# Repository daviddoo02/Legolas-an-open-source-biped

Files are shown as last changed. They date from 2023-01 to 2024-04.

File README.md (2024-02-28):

# Legolas - An Open Source Bipedal Robot

Legolas is a mini bipedal robot inspired by the Cassie by Agility Robotics. The project aims to provide an open-source platform for learning and applying reinforcement learning in robotics.

<p align="center">
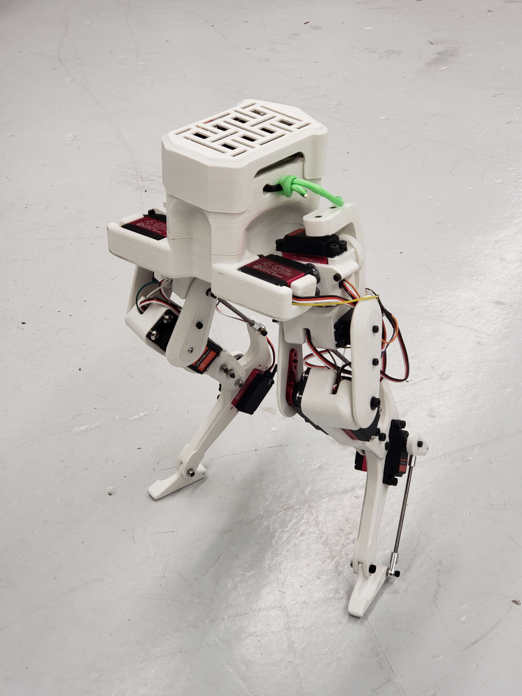
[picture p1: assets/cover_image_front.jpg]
  
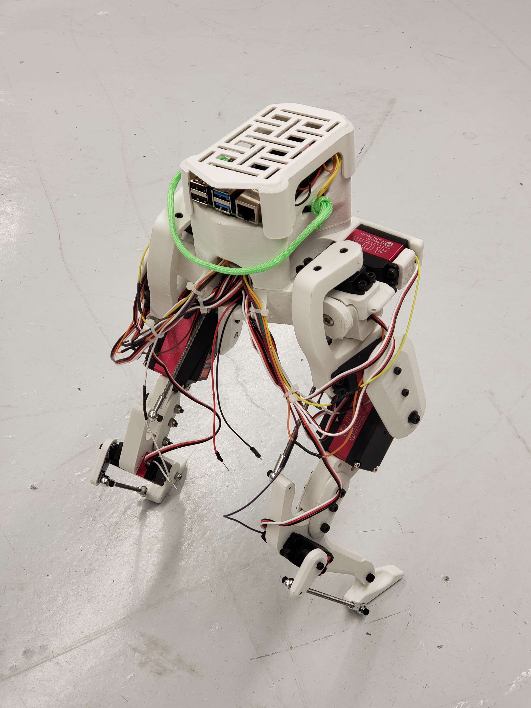
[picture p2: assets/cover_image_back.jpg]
  
</p>

<p align="center">
  <a href="assets/Walking_Test_3.mp4">Video 3</a>
</p>

## Repository Contents

This repository contains CAD files and 3D printing files for Legolas. 

The code for the robot is available at [Legolas Controller](https://github.com/daviddoo02/Legolas_Controller).

## Getting Started

1. **Clone this repository:**

    ```bash
    git clone https://github.com/daviddoo02/Legolas-an-open-source-biped/
    ```

2. **Modify the CAD files:**

    Modify the CAD files to fit your specific needs using Solidworks.

3. **3D Print your own robot:**

    Alternatively, use the provided STL files located in `CAD/Legolas/V2/STLs` to 3D print your own robot.

4. **Assemble the robot and have fun!**

## Required Materials

Materials and components used are listed and linked below.

### Main Body

1. [3D printing filament x 1 kg](https://www.amazon.com/dp/B089S1HB8K)
2. [Metric Nuts and Bolts](https://www.amazon.com/Assortment-M2-M3-M4-M5/dp/B0CBMMPPKF)
3. [Metric Locknuts](https://www.amazon.com/dp/B0CHVTYLWC)
4. [Thrust Bearings](https://www.amazon.com/gp/product/B08FHTD8VT)
5. [Ball joint rod end](https://www.amazon.com/gp/product/B0828T1NNW)
6. [M4 threaded rod](https://www.amazon.com/gp/product/B01MAYQ12S)

### Electronics

1. [Raspberry Pi 4](https://www.amazon.com/Raspberry-Model-2019-Quad-Bluetooth/dp/B07TC2BK1X)
2. [PCA9685 Servo Driver Board](https://www.amazon.com/gp/product/B07BRS249H)
3. [40 kg Hobby Servos x 8](https://www.amazon.com/Servo-Torque-Waterproof-Degree-Compatible/dp/B0C95YMMQS)
4. [80 kg Hobby Servos x 2](https://www.amazon.com/GoolRC-Digital-Torque-Waterproof-Replacements/dp/B0B5H4MWZG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)
5. [MPU6050 IMU](https://www.amazon.com/Acceleration-Sensors-Accelerometer-Three-Axis-Quadcopter/dp/B07V67DQ5N)
6. [ADS1115 ADC](https://www.amazon.com/gp/product/B07VPFLSMX)
7. [Jumper Wires](https://www.amazon.com/Elegoo-EL-CP-004-Multicolored-Breadboard-arduino/dp/B01EV70C78)
8. [Power DIY Connector](https://www.amazon.com/dp/B09S3S6RYC)
9. [USB C Connector](https://www.amazon.com/dp/B0CCJRWKC5)
10. [4 to 1 Wire Connector](https://www.amazon.com/dp/B0B28GNVGZ)

## Assembly Instruction

Instructions and examples for assembling Legolas will be added in future updates.

## License

This project is licensed under the MIT License - see the [LICENSE](LICENSE) file for details.

## Acknowledgments

- Inspired by the Cassie robot by Agility Robotics.
- Solidworks was used for the physical design of the robot.

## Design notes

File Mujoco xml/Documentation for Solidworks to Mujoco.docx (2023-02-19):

Documentation for Solidworks to Mujoco:

1. Exporting from Solidworks using SW2URDF:
  a. Step 1: Download SW2URDF extension
    i. Repo: https://github.com/ros/solidworks_urdf_exporter/releases
  b. Step 2: Assigning frames to your robot
    i. (170) Frame Assignment For Robotic Manipulators - Direct Kinematics I - YouTube (https://www.youtube.com/watch?v=fNIyNF87q9I&t=244s)
    ii. ^ this video should give you a good idea of what assigning frames is and how to know where to place your frames.
    iii. Use the Reference geometry → Coordinate system tool in Solidworks.
      1. A useful tip: Point your coordinate systems toward each other if possible – this will make it easier to code in mujoco later.
  c. Step 3: Using the extension
    i. Follow this video tutorial: https://www.youtube.com/watch?v=ge3P307TgJI
    ii. Now you should have a folder with the URDF of your robot.
2. Accessing the URDF and verifying the urdf:
  a. Ref:
    i. https://mujoco.readthedocs.io/en/latest/modeling.html#curdf
    ii. urdf - ROS Wiki (http://wiki.ros.org/urdf)
  b. Step 1: Checking if your URDF generated correctly:
    i. Add the mujoco extension after robot name like so:

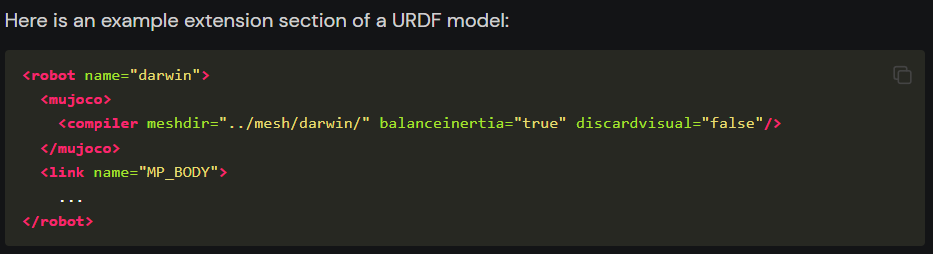
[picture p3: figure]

  c. Step 2: Check the URDF for collision/joint problems:
    i. After you add the extension, you should be able to drag and drop the file into mujoco and 2 things can happen:
      1. Everything runs < less interesting
      2. Everything runs itself apart < more interesting
        a. If this was the case, you could be running into a collision issue.
        b. You can confirm this by tapping F to toggle the forces vectors and H to toggle the convex hull

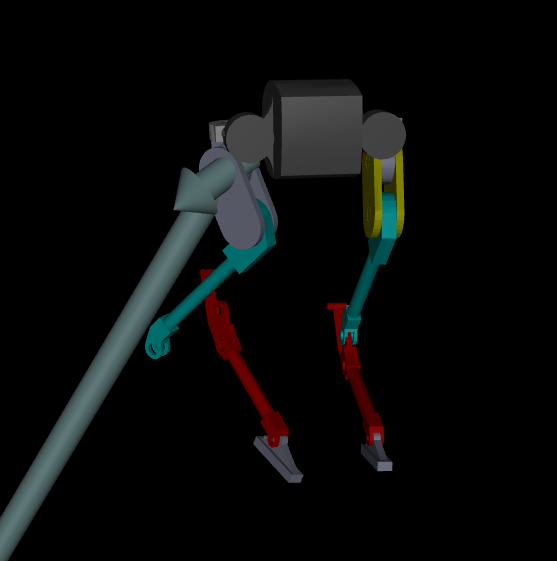
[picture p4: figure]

          ii. So, as you can see, there is a huge force coming off the body and the knee joint not being connected.
    ii. Fixing Joints:
      1. Go back to Solidworks and check how the urdf was generated, make sure all the frames and joint types are correct and regenerate the urdf.
    iii. Fixing collision:
      1. Check which part is colliding by hitting the H-key on your keyboard.
        a. Note: if a collision geometry was not specified, mujoco will automatically generate it, but it messes up sometimes.
      2. Solution: in the URDF, replace the collision mesh with something else by changing the name of the collision geometry mesh to the new mesh.
  d. Step 3: Verifying your URDF on Linux:
    i. Use the following command on Linux terminal to verify the URDF:
      1. rosrun urdfdom check_urdf /path2model/<model>.urdf
    ii. This should output the kinematic tree of your robot.

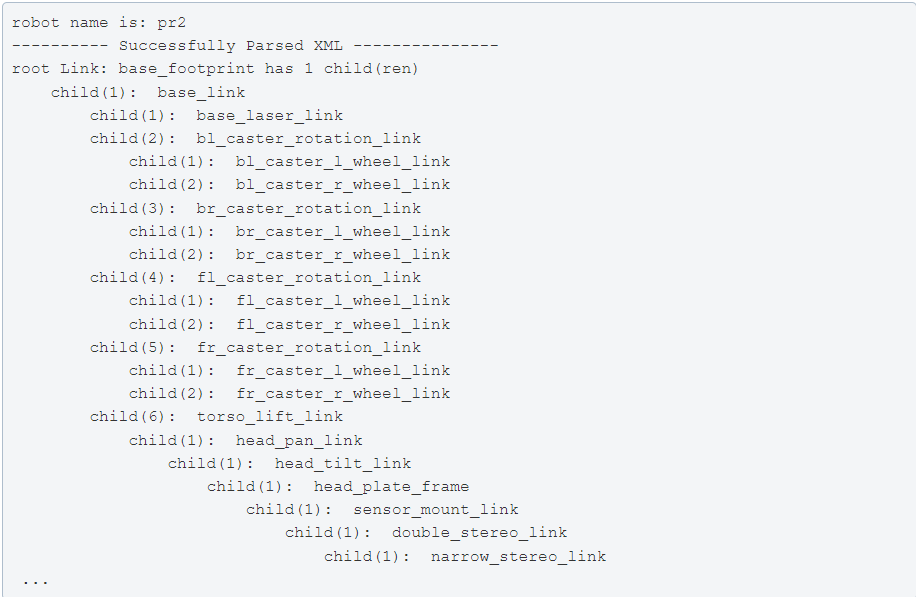
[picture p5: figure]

3. Converting URDF to MUJOCO xml:
  a. Ref:
    i. wangcongrobot/dual_ur5_husky_mujoco: Dual UR5 Husky Robot MuJoCo Model (github.com) (https://github.com/wangcongrobot/dual_ur5_husky_mujoco)
  b. Enter the path ~/mujoco/mujoco200/bin first and run command below:
  c. Convert the urdf:
    i. compile /path/to/model.urdf /path/to/model.xml
  d. Test:
    i. mujoco200/bin$ ./simulate /path/to/model.xml

Congratulations! You are now able to run mujoco with your robot design! Add more mujoco tags as needed

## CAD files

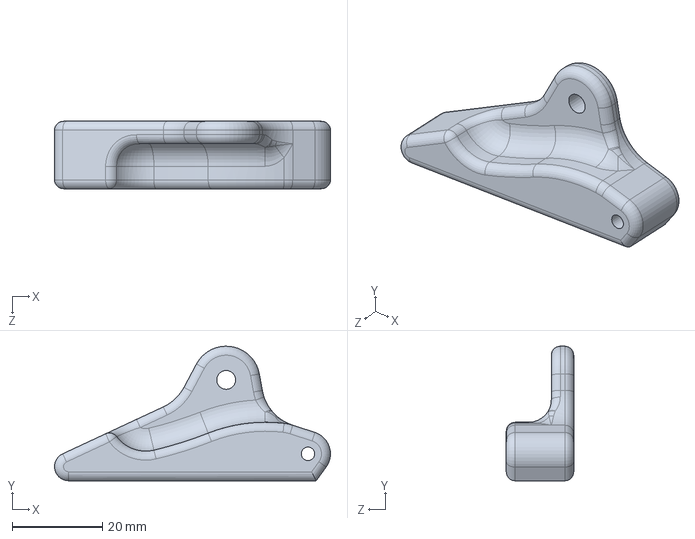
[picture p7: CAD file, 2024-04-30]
CAD/Legolas/V3/Foot v3.SLDPRT
61.3 x 29.9 x 15.0 mm

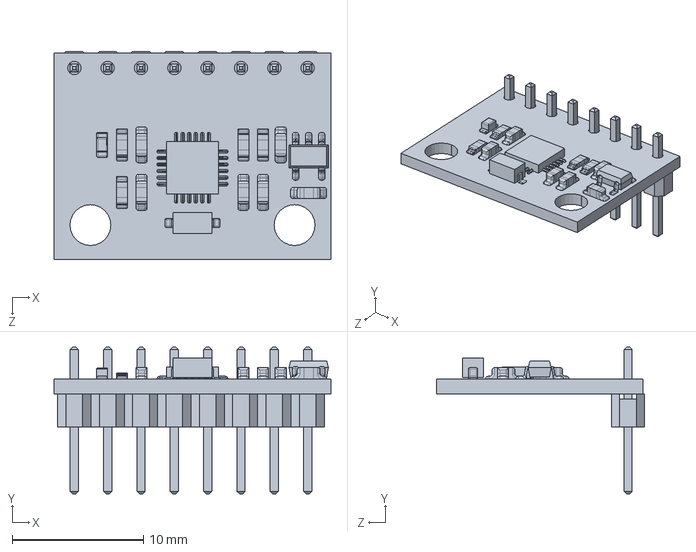
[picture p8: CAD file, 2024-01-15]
CAD/Servo and electronics/MPU 6050 IMU.SLDPRT
21.1 x 11.2 x 15.9 mm

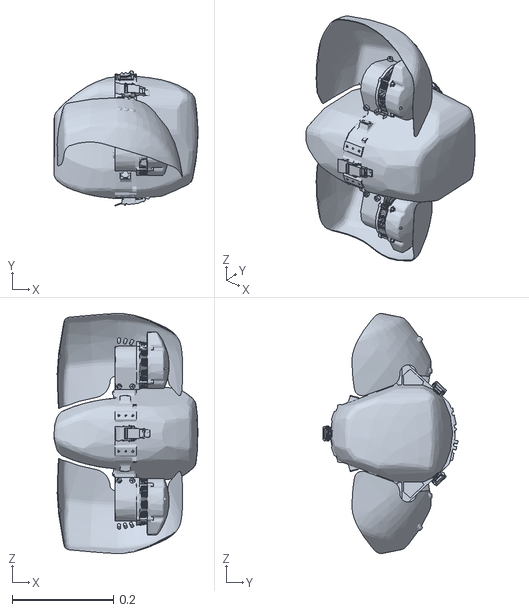
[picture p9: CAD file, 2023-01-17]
Mujoco xml/References/agility_cassie/assets/pelvis.obj
0.284 x 0.267 x 0.474

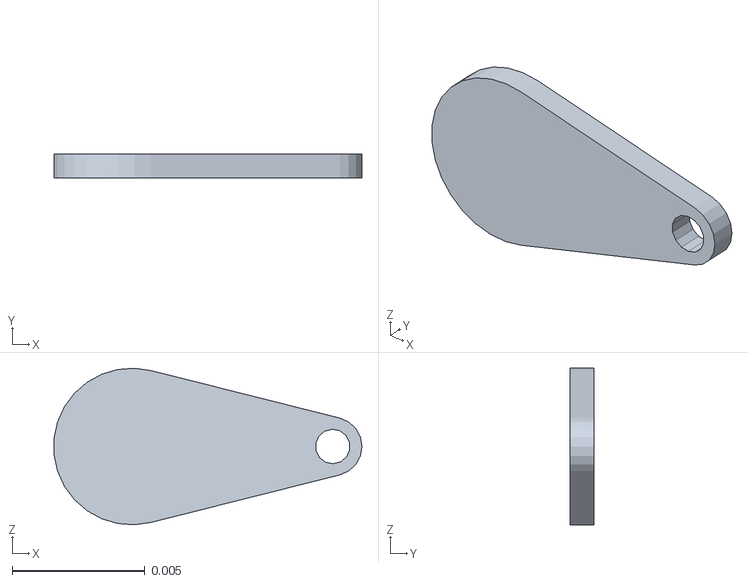
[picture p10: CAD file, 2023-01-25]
Working Mk 5/meshes/R_Servo_collision.STL
0.0116 x 0.000898 x 0.00589

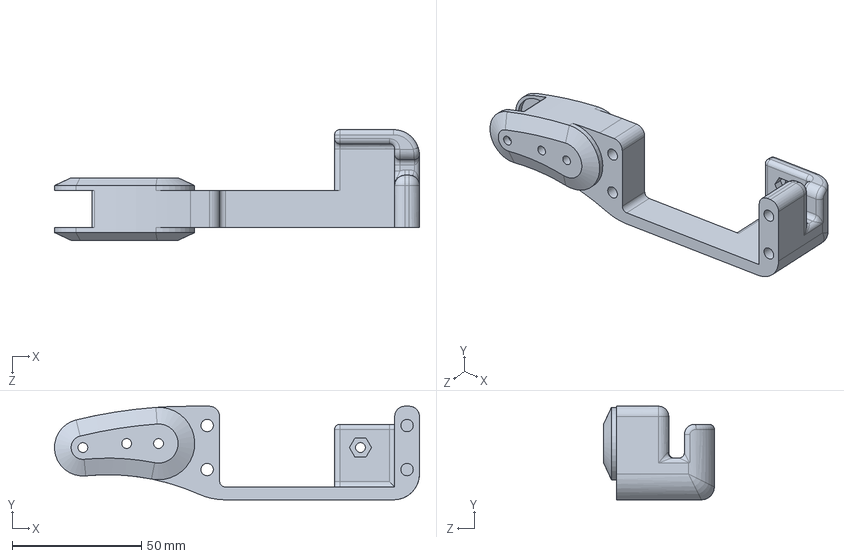
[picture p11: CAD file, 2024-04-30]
CAD/Legolas/V3/Foreleg v3.SLDPRT
141.0 x 36.2 x 42.8 mm

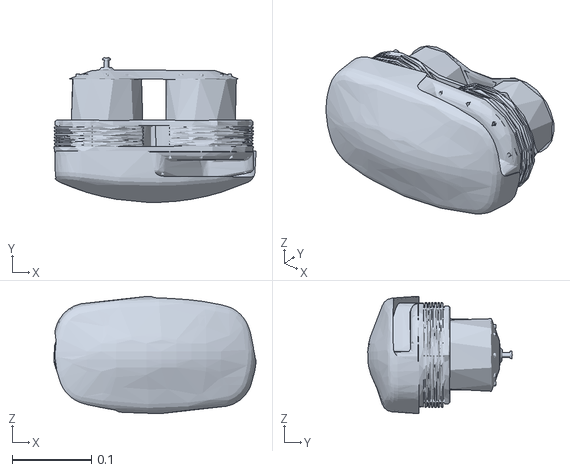
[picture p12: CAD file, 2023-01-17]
Mujoco xml/References/agility_cassie/assets/hip-pitch.obj
0.256 x 0.183 x 0.149

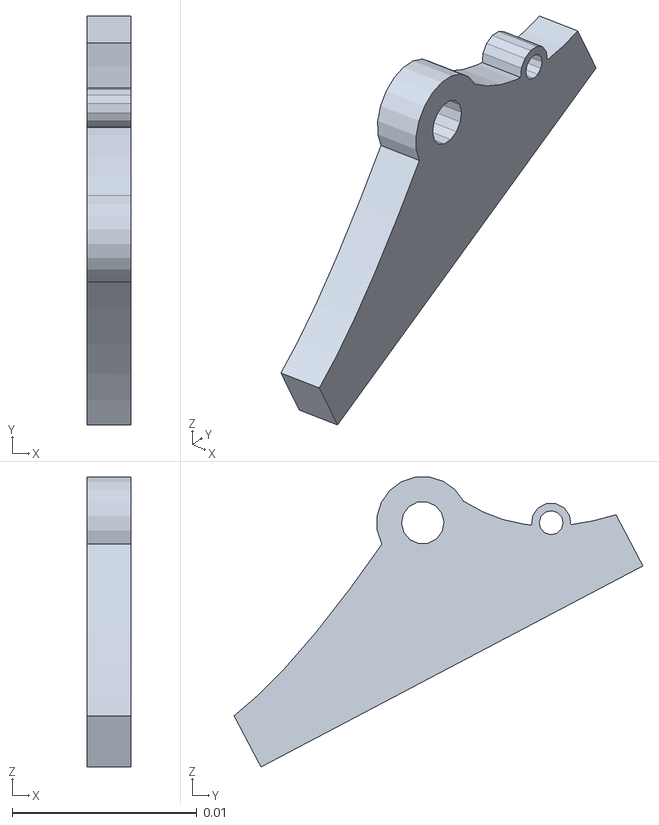
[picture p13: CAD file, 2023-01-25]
Working Mk 5/meshes/R_Foot_collision.STL
0.0024 x 0.0221 x 0.0157

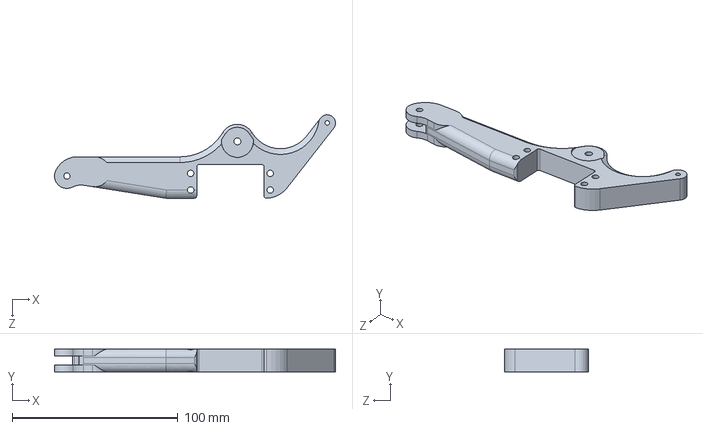
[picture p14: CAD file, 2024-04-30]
CAD/Legolas/V3/Shin v3.SLDPRT
169.4 x 13.7 x 50.4 mm

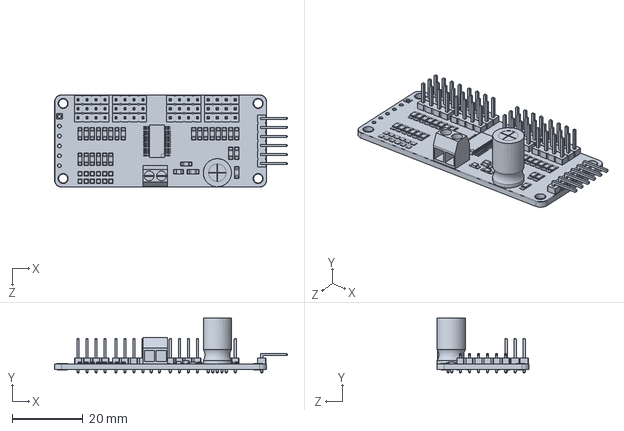
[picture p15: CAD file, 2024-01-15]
CAD/Servo and electronics/servo driver pca9685.SLDPRT
66.1 x 15.6 x 26.2 mm

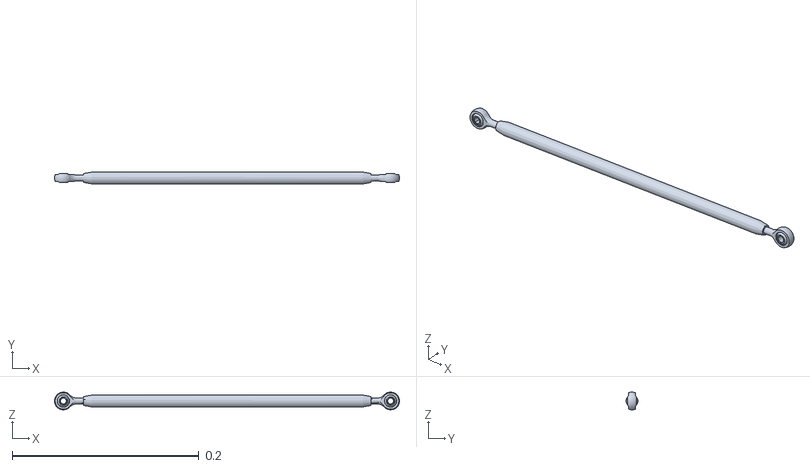
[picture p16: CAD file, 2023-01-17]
Mujoco xml/References/agility_cassie/assets/plantar-rod.obj
0.369 x 0.0127 x 0.0191

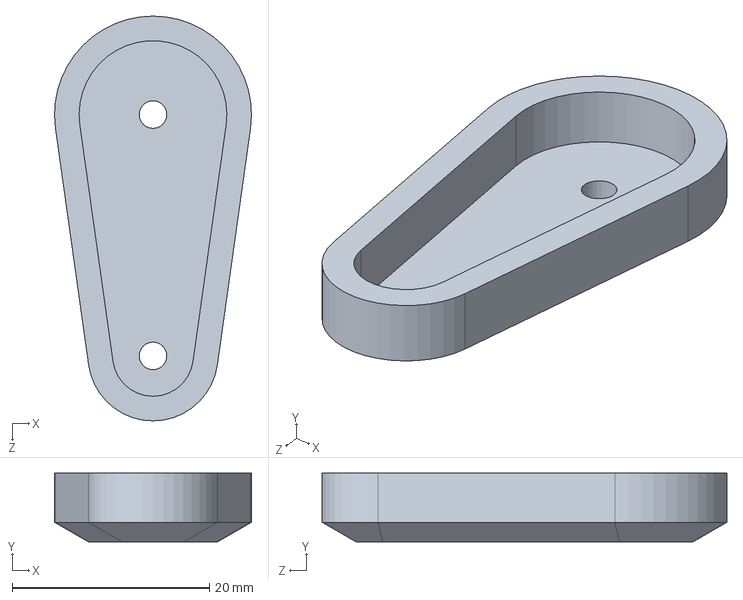
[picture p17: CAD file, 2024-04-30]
CAD/Legolas/V3/Servo Cover v3.SLDPRT
20.0 x 7.00 x 41.1 mm

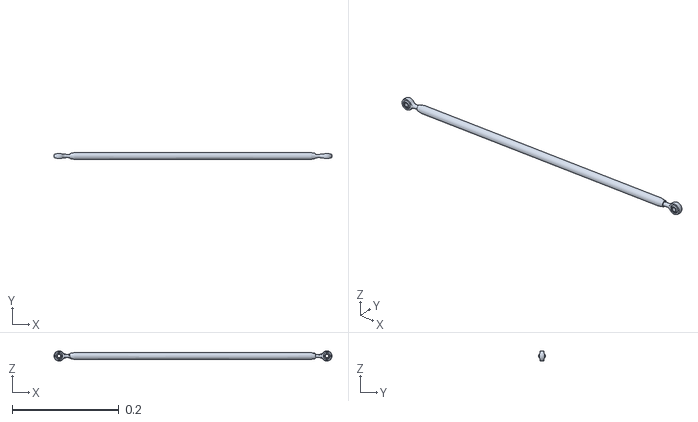
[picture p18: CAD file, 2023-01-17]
Mujoco xml/References/agility_cassie/assets/achilles-rod.obj
0.52 x 0.0128 x 0.0191

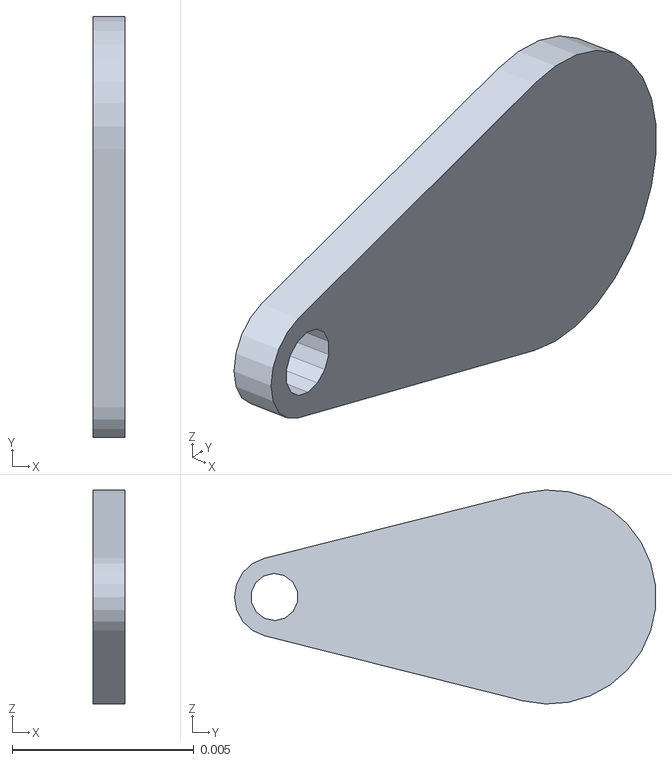
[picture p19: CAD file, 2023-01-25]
Working Mk 5/meshes/L_Servo_collision.STL
0.000871 x 0.0116 x 0.00589

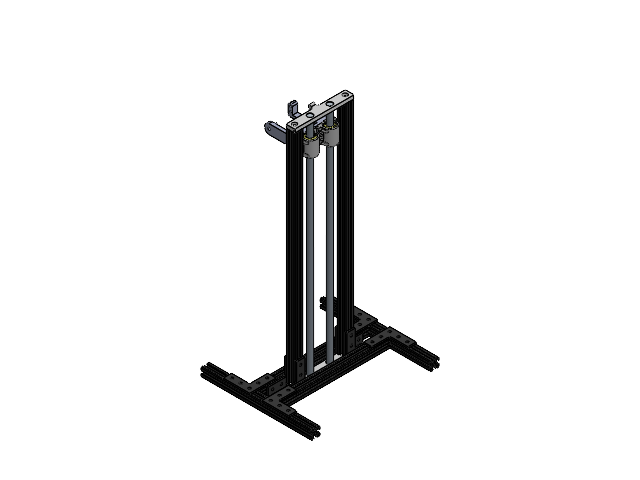
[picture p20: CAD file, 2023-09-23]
CAD/Test_Bench/Test_Bench_Mk2.SLDASM
90 deg flat plate^Test_Bench_Mk2 x 8
2020 series extrusion 50 cm^Test_Bench_Mk2 x 2
25 cm^Test_Bench_Mk2 x 4
12mm rail^Test_Bench_Mk2 x 2
Rail Adapter^Test_Bench_Mk2 x 2
Rail Interface A^Test_Bench_Mk2
Rail Interface B^Test_Bench_Mk2
Test Bench Adaptor v1^Test_Bench_Mk2

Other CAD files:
CAD Tree/David's cardboard box/Assembly 1.SLDASM
CAD/Servo and electronics/Mirror40 kg Servo.SLDPRT
Working Mk 5/meshes/L_Foot_collision.STL
CAD/Servo and electronics/Mirror80kg_servo.SLDPRT
CAD/Legolas/V2/Foot.SLDPRT
CAD/Legolas/V2/Foreleg.SLDPRT
CAD/Legolas/V2/Hip Pitch.SLDPRT
CAD/Legolas/V2/Hip Roll.SLDPRT
CAD/Legolas/V2/Hip Yaw.SLDPRT
CAD/Legolas/V2/STLs/Foot.STL
CAD/Legolas/V2/STLs/Foreleg A.STL
CAD/Legolas/V2/STLs/Foreleg B.STL
CAD/Legolas/V2/STLs/Foreleg C.STL
CAD/Legolas/V2/STLs/Hip 1 A.STL
CAD/Legolas/V2/STLs/Hip 1 B.STL
CAD/Legolas/V2/STLs/Hip 2.STL
CAD/Legolas/V2/STLs/Hip Pitch A.STL
CAD/Legolas/V2/STLs/Hip Pitch B.STL
CAD/Legolas/V2/STLs/Main body ADC Mount.STL
CAD/Legolas/V2/STLs/Main body Wire Connector Container.STL
CAD/Legolas/V2/STLs/Main body cover.STL
CAD/Legolas/V2/STLs/Main body.STL
CAD/Legolas/V2/STLs/Servo Cover.STL
CAD/Legolas/V2/STLs/Shin.STL
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

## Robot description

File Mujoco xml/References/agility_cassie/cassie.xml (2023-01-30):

<mujoco model="cassie">
  <compiler eulerseq="zyx" meshdir="assets" texturedir="assets" autolimits="true"/>

  <option timestep="0.0005"/>
  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

  <default>
    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
    <equality solref="0.005 1"/>
    <default class="cassie">
      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
    </default>
    <default class="collision">
      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
      <default class="collision-left">
        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
      </default>
      <default class="collision-right">
        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
      </default>
    </default>
  </default>

  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

  <worldbody>
    <light name="spotlight" mode="targetbodycom" target="cassie-pelvis" pos="0 -1 2"/>
    <body name="cassie-pelvis" pos="0 0 1.1" childclass="cassie">
      <camera name="track" pos="0 -3 1" zaxis="0 -1 0.5" mode="track"/>
      <inertial pos="0.05066 0.000346 0.02841" mass="10.33" fullinertia="0.085821 0.049222 0.08626 1.276e-05 -0.00016022 -0.000414"/>

      <freejoint/>

      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
      
      <body name="left-hip-roll" pos="0.021 0.135 0" xyaxes="0 0 -1 0 1 0">
        <inertial pos="-0.01793 0.0001 -0.04428" mass="1.82" fullinertia="0.003431 0.003793 0.002135 -6.65e-07 -0.00084 3.99e-06"/>
        <joint name="left-hip-roll" type="hinge" range="-15 22.5" damping="1" armature="0.038125"/>
        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
        <body name="left-hip-yaw" pos="0 0 -0.07" xyaxes="0 0 1 0 1 0">
          <inertial pos="0 -1e-05 -0.034277" mass="1.171" fullinertia="0.002443 0.002803 0.000842 -4e-08 2.462e-07 -2.71e-08"/>
          <joint name="left-hip-yaw" type="hinge" range="-22.5 22.5" damping="1" armature="0.038125"/>
          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
          <body name="left-hip-pitch" pos="0 0 -0.09" xyaxes="0 0 -1 1 0 0">
            <inertial pos="0.05946 5e-05 -0.03581" mass="5.52" fullinertia="0.010898 0.029714 0.030257 -0.0002669 -5.721e-05 9.17e-06"/>
            <joint name="left-hip-pitch" type="hinge" range="-50 80" damping="1" armature="0.09344"/>
            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
            <body name="left-achilles-rod" pos="0 0 0.045" xyaxes="0.7922 -0.60599 -0.072096 0.60349 0.79547 -0.054922">
              <inertial pos="0.24719 0 0" mass="0.1567" fullinertia="3.754e-06 0.004487 0.004488 -3.74e-08 -1.61e-08 0"/>
              <joint name="left-achilles-rod" type="ball" damping="0.01"/>
              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
            </body>
            <body name="left-knee" pos="0.12 0 0.0045" xyaxes="0.70711 -0.70711 0 0.70711 0.70711 0">
              <inertial pos="0.023 0.03207 -0.002181" mass="0.7578" fullinertia="0.001376 0.0010335 0.0021637 -0.00039744 -4.085e-05 -5.374e-05"/>
              <joint name="left-knee" type="hinge" ref="-45" range="-164 -37" damping="1" armature="0.09344"/>
              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
              <body name="left-knee-spring" pos="0.06068 0.08241 0">
                <inertial pos="0.0836 0.0034 0" mass="0.186" fullinertia="5.215e-05 0.00041205 0.0003669 6.87e-06 0 0"/>
                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
              </body>
              <body name="left-shin" pos="0.06068 0.04741 0">
                <inertial pos="0.18338 0.001169 0.0002123" mass="0.577" fullinertia="0.00035939 0.014728 0.014707 -0.00020981 2.266e-05 -1.2e-07"/>
                <joint name="left-shin" type="hinge" range="-20 20" stiffness="1500" damping="0.1"/>
                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
                <body name="left-tarsus" pos="0.43476 0.02 0" xyaxes="0.52992 0.84805 0 -0.84805 0.52992 0">
                  <inertial pos="0.11046 -0.03058 -0.00131" mass="0.782" fullinertia="0.00039238 0.013595 0.013674 0.00023651 -4.987e-05 -4.82e-06"/>
                  <joint name="left-tarsus" type="hinge" ref="58" range="50 170" damping="0.1"/>
                  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
                  <body name="left-heel-spring" pos="-0.01269 -0.03059 0.00092" xyaxes="-0.91211 0.40829 0.036948 -0.40992 -0.90952 -0.068841">
                    <inertial pos="0.081 0.0022 0" mass="0.126" fullinertia="2.959e-05 0.00022231 0.0002007 7.15e-06 -6e-07 1e-07"/>
                    <joint name="left-heel-spring" type="hinge" stiffness="1250"/>
                    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
                  </body>
                  <body name="left-foot-crank" pos="0.058 -0.034 0.02275">
                    <inertial pos="0.00493 2e-05 -0.00215" mass="0.1261" fullinertia="2.6941e-05 4.9621e-05 6.3362e-05 -2.1e-09 -3.9623e-06 -1.09e-08"/>
                    <joint name="left-foot-crank" type="hinge" range="-140 -30" damping="1"/>
                    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
                    <body name="left-plantar-rod" pos="0.055 0 -0.00791">
                      <inertial pos="0.17792 0 0" mass="0.1186" fullinertia="2.779e-06 0.001774 0.001775 -2.34e-08 -8.1e-09 0"/>
                      <joint name="left-plantar-rod" type="hinge"/>
                      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
                    </body>
                  </body>
                  <body name="left-foot" pos="0.408 -0.04 0">
                    <inertial pos="0.00474 0.02748 -0.00014" mass="0.1498" fullinertia="0.00017388 0.00016793 0.00033261 0.00011814 1.36e-06 -4e-07"/>
                    <joint name="left-foot" type="hinge" range="-140 -30" damping="1" armature="0.01225"/>
                    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
                  </body>
                </body>
              </body>
            </body>
          </body>
        </body>
      </body>
      <body name="right-hip-roll" pos="0.021 -0.135 0" xyaxes="0 0 -1 0 1 0">
        <inertial pos="-0.01793 0.0001 -0.04428" mass="1.82" fullinertia="0.003431 0.003793 0.002135 6.65e-07 -0.00084 -3.99e-06"/>
        <joint name="right-hip-roll" type="hinge" range="-22.5 15" damping="1" armature="0.038125"/>
        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
        <body name="right-hip-yaw" pos="0 0 -0.07" xyaxes="0 0 1 0 1 0">
          <inertial pos="0 1e-05 -0.034277" mass="1.171" fullinertia="0.002443 0.002803 0.000842 4e-08 2.462e-07 2.71e-08"/>
          <joint name="right-hip-yaw" type="hinge" range="-22.5 22.5" damping="1" armature="0.038125"/>
          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
          <body name="right-hip-pitch" pos="0 0 -0.09" xyaxes="0 0 -1 1 0 0">
            <inertial pos="0.05946 5e-05 0.03581" mass="5.52" fullinertia="0.010898 0.029714 0.030257 -0.0002669 5.721e-05 -9.17e-06"/>
            <joint name="right-hip-pitch" type="hinge" range="-50 80" damping="1" armature="0.09344"/>
            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
            <body name="right-achilles-rod" pos="0 0 -0.045" xyaxes="0.7922 -0.60599 0.072096 0.60349 0.79547 0.054922">
              <inertial pos="0.24719 0 0" mass="0.1567" fullinertia="3.754e-06 0.004487 0.004488 -3.74e-08 1.61e-08 0"/>
              <joint name="right-achilles-rod" type="ball" damping="0.01"/>
              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
            </body>
            <body name="right-knee" pos="0.12 0 -0.0045" xyaxes="0.70711 -0.70711 0 0.70711 0.70711 0">
              <inertial pos="0.023 0.03207 0.002181" mass="0.7578" fullinertia="0.001376 0.0010335 0.0021637 -0.00039744 4.085e-05 5.374e-05"/>
              <joint name="right-knee" type="hinge" ref="-45" range="-164 -37" damping="1" armature="0.09344"/>
              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
              <body name="right-knee-spring" pos="0.06068 0.08241 0">
                <inertial pos="0.0836 0.0034 0" mass="0.186" fullinertia="5.215e-05 0.00041205 0.0003669 6.87e-06 0 0"/>
                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
              </body>
              <body name="right-shin" pos="0.06068 0.04741 0">
                <inertial pos="0.18338 0.001169 -0.0002123" mass="0.577" fullinertia="0.00035939 0.014728 0.014707 -0.00020981 -2.266e-05 1.2e-07"/>
                <joint name="right-shin" type="hinge" range="-20 20" stiffness="1500" damping="0.1"/>
                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
                <body name="right-tarsus" pos="0.43476 0.02 0" xyaxes="0.52992 0.84805 0 -0.84805 0.52992 0">
                  <inertial pos="0.11046 -0.03058 0.00131" mass="0.782" fullinertia="0.00039238 0.013595 0.013674 0.00023651 4.987e-05 4.82e-06"/>
                  <joint name="right-tarsus" type="hinge" ref="58" range="50 170" damping="0.1"/>
                  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
                  <body name="right-heel-spring" pos="-0.01269 -0.03059 -0.00092" xyaxes="-0.91211 0.40829 -0.036948 -0.40992 -0.90952 0.068841">
                    <inertial pos="0.081 0.0022 0" mass="0.126" fullinertia="2.959e-05 0.00022231 0.0002007 7.15e-06 6e-07 -1e-07"/>
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

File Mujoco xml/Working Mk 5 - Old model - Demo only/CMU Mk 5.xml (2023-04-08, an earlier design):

<mujoco model="CMU Mk 5">
  <compiler angle="radian" meshdir="meshes/" autolimits="true"/>
  
  <option timestep="0.005" gravity="0 0 0"/>

  <default/>

  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
  
  <worldbody>
    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
    
    <light name="spotlight" mode="targetbodycom" target="base link" pos="0 6 4" castshadow="false"/>
    
    <body name="base link" pos="0 0 .2">    
      <camera name="track" pos="0 -3 1" zaxis="0 -1 0.5" mode="track"/>
      <inertial pos="0 0 0" mass="0.0299227589680342" fullinertia="4.64430780114595E-06 4.78982197003375E-06 5.96248441172554E-06 -7.0005651433527E-12 1.45948993644989E-11 -7.65792898200085E-08"/>
      
      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      
      
      <body name="R_Hip_1" pos="0.021005 0 0" quat="0.706765 0.706768 -0.0219327 0.0219327">
        <inertial pos="-3.00471e-07 -4.83658e-06 0.00581975" quat="0.707107 0 0 0.707107" mass="0.000490673" diaginertia="1.27003e-08 9.79961e-09 4.84291e-09"/>
        
        <joint name="R_Hip_1" type="hinge" pos="0 0 0" axis="0 0 1"/>
        
        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
        
        <body name="R_Hip_2" pos="0 0 0.0076962" quat="0.529268 0.52927 0.468907 -0.468908">
          <inertial pos="-1.39156e-10 -1.14679e-09 0.0107683" quat="0.707107 0 0 0.707107" mass="0.00100456" diaginertia="4.56705e-08 3.43974e-08 1.53565e-08"/>
          
          <joint name="R_Hip_2" type="hinge" pos="0 0 0" axis="0 0 1"/>
          
          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
          
          <body name="R_Thigh" pos="0 0 0.013139" quat="0.397507 0.584796 0.584798 0.397509">
            <inertial pos="3.40459e-05 0.009 0" quat="0.707107 0.707107 0 0" mass="0.00259524" diaginertia="2.57116e-07 2.17945e-07 5.47709e-08"/>
            
            <joint name="R_Thigh" type="hinge" pos="0 0 0" axis="-1 0 0"/>
            
            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
            
            <body name="R_Foreleg" pos="0 0.018 0" quat="-1.92102e-06 3.13083e-06 -0.852343 0.522982">
              <inertial pos="0 0.0208617 -0.00148561" quat="0.684738 0.728789 0 0" mass="0.00244939" diaginertia="1.23016e-06 1.2006e-06 3.92157e-08"/>
              
              <joint name="R_Foreleg" type="hinge" pos="0 0 0" axis="-1 0 0" limited="true" range="-5 100" damping="0"/>
              
              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

              <body name="R_Shin" pos="0 0.064516 0" quat="0.868737 -0.495274 0 0">
                <inertial pos="4.16582e-05 0.0220307 -0.00550832" quat="0.819399 0.572189 -0.0177322 0.029512" mass="0.00129205" diaginertia="4.33834e-07 4.29412e-07 9.31982e-09"/>
                
                <joint name="R_Shin" type="hinge" pos="0 0 0" axis="-1 0 0"/>
                
                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

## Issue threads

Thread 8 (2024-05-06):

TypeError: pol2cart() missing 1 required positional argument: 'phi'

TextZip, 2024-05-06:
Hi @daviddoo02 ,

Thanks a lot for this amazing work. I went through the Leg Static Analysis notebook and tried running it using Google Colab. It looks like the pol2cart() method requires three parameters and only two are being provided.

Got the following error:
```bash
---------------------------------------------------------------------------
TypeError                                 Traceback (most recent call last)
[<ipython-input-8-7e677afad58a>](https://localhost:8080/#) in <cell line: 1>()
----> 1 j1,j2,j3,j4,j5 = forward_kinematics(60, 120)
      2
      3 # Create 3D plot
      4 fig = plt.figure()
      5 ax = fig.add_subplot()

[<ipython-input-7-282f80d4137f>](https://localhost:8080/#) in forward_kinematics(th1, th2)
     24
     25     j1 = np.array([0, 0])
---> 26     j2 = j1 + pol2cart(l1, th1)
     27     j3 = j2 + pol2cart(l2, th1 + th2)
     28

TypeError: pol2cart() missing 1 required positional argument: 'phi'
```

Could you also please give some information about what the static analysis is being used for here ? I have seen some static analysis tools in CAD software like solidworks and such but I never came across this pythonic way of doing things.

TIA

daviddoo02, 2024-05-07:
Hey @TextZip, the reason it's asking for 3 arguments is because I was trying to get it to work in 3D. I was running a static analysis using anastruct to calculate how to scale each linkages so that my servos (40 & 80 kgcm) can support it. The number it gave me wasn't quite as reliable as I expected so I went with a best guess and figure it out experimentally.

Closed 2024-09-03.

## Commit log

2023-01-08 Updated Mk 3 URDF
    [CMU.urdf, Cassie_mock_up_mjc.xml]
2023-01-08 Added mujoco extension
    [CMU3.urdf]
2023-01-09 Fixed Collision problem - added documentation
    [Base Link.SLDPRT, CMU.urdf, CMU3.urdf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]
2023-01-24 Updated CADs
    Updated CADs, include linkages and servos
    [CMU.SLDASM, ForeShin.SLDPRT, L Feet.STL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]
2023-01-24 New URDF with more Links
    New links
    [CMU.SLDASM, CMU.SLDASM.csv, CMU.SLDASM.urdf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]
2023-01-25 URDF Mk 5 completed
    [CMU MK 4.urdf, CMU Mk 5.csv, CMU Mk 5.urdf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]
2023-01-25 Added Collision Files
    [L_Foot_collision.STL, L_Servo_collision.stl, R_Foot_collision.stl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]
2023-01-25 Fixing Collision
    [R_Servo_collision.stl]
2023-01-30 Added equality constraint
    [CMU.SLDASM, L_Foot.STL, L_Foot_collision.STL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]
2023-02-03 Created CAD Folder
    [leg_v2.SLDASM]
2023-02-03 Renamed servo file
2023-04-02 Lower Leg CAD
    Remade the foot up to the knee
    [Base Link.SLDPRT, CMU.SLDASM, Foot.SLDPRT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]
2023-04-02 Sophia's stuff
    [NewTestAssem.SLDASM, new_foot.SLDPRT]
2023-04-08 Added David's RL stuff
    [CMU.SLDASM]
2023-04-22 Add files via upload
    Is it back again?
    [Bar Attachment.SLDPRT, Bar Interface.SLDPRT, Hip Assembly.SLDASM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]
2023-05-17 Reorganized and added some stuff
    Added some stuff
    [60355K505_Ball Bearing.SLDPRT, Assembly 1.SLDASM, Bar Attachment.SLDPRT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]
2023-05-19 New Assembly in David's cardboard boxf
    dsa
    [Newer_New_Shin_Upper.SLDPRT, new_thigh.SLDPRT]
2023-05-22 Updated assembly
    [M4 Ball Joint Rod End.SLDPRT, M4 Connecting Rod.SLDPRT, M5 Ball Joint Rod End.SLDPRT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]
2023-05-24 Finished Prelim Assembly
    [Test Bench Assembly.SLDASM]
2023-06-01 First leg prototype done!
    [Adaptor.STL, Ankle x 2.STL, Foot A.STL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]
2023-06-03 Updated Assembly 1
    [Foreleg upper A.STL, Hip 1 A.STL, Hip 1 B.STL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]
2023-06-26 updated parts
    [Foreleg lower x 2.STL, Shin A.STL, Shin B.STL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]
2023-07-01 Updated CAD w thrust bearings
    [Ankle v2.STL, Base Link.SLDPRT, CMU.SLDASM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]
2023-07-12 URDF Testing
    [Adaptor.STL, Ankle v2.STL, Ankle x 2.STL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]
2023-07-14 Clean up!
    [Base Link.SLDPRT, Base.SLDPRT, CMU MK 4.urdf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]
2023-08-20 Updated Cad with 80 kg servo
    [80kg_servo.SLDPRT, 80kg_servo_arm.SLDPRT, Foreleg upper mk 2 A.STL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]
2023-09-23 Updated CAD
    [60355K505_Ball Bearing.SLDPRT, ADS1115.SLDPRT, Base Link.SLDPRT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]
2023-09-23 Updated CAD again
    [Foot.SLDPRT, Test_Bench_Mk2.SLDASM]
2023-11-08 Cleaned up + added README
    [80kg_servo.SLDPRT, 80kg_servo_arm.SLDPRT, ADS1115.SLDPRT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]
2024-01-15 V2 CAD updated!
    [40 kg Servo Arm.SLDPRT, 40 kg Servo.SLDPRT, 80kg_servo.SLDPRT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]
2024-04-30 Liz Updates
    Hmm maybe this will work
    [Foot v3.SLDPRT, Foreleg v3.SLDPRT, Foreleg.SLDPRT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]
2024-05-04 Added shoes
    [Foot.SLDPRT, Hip Pitch A.STL, Hip Pitch B.STL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]
